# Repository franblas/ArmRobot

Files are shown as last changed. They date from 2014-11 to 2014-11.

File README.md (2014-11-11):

# ArmRobot Project
The ArmRobot project aims to build and control a functional robotic arm using servo motors.
Project realized by Luc F. and Francois B. 

## The C library for STM32 card
A [C library](STM32/) has been developed to communicate with servo motors and control the arm as a whole through a STM32 electronic card.

## The Arduino library for Arduino card
An [Arduino](Arduino/) library has been developed to debug servo motors through an Arduino electronic card.

## Theorical code
A [Matlab](Matlab/) implementation has been done to compute equations for angles, based on the theory of Denhavit-Artenberg.

## Solidworks model
We have built the arm from scratch. [Here] (Solidworks/) you can find the whole model on solidworks we have realized, with every part of the arm.

## Joystick
Move an arm robot is cool, but with a joystick it's cooler ! [Here] (PCB_Joystick/) you can can find the pcb of the joystick, realized with Eagle.

## Project rapport
You can find the whole project rapport in pdf format [here] (https://github.com/franblas/ArmRobot/blob/master/Doc/compte_rendu_bras_de_robot.pdf?raw=true) (It's in french).

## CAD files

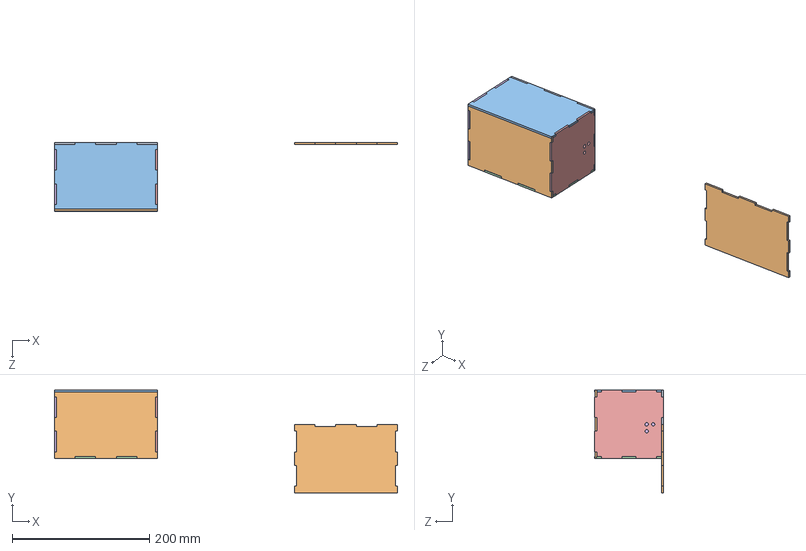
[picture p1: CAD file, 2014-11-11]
Solidworks/piecesassembleesphoto2.SLDASM
499.4 x 150.0 x 100.0 mm
dessous
dessus x 2
arriere1
facegauche1
facedroite1

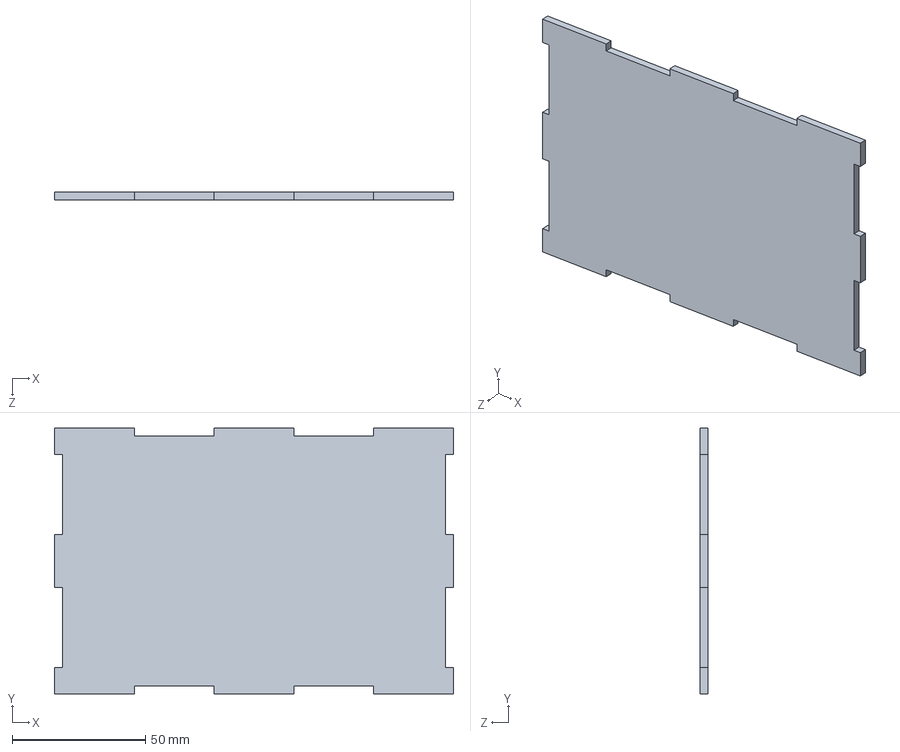
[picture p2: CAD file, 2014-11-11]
Solidworks/dessous.SLDPRT
150.0 x 100.0 x 3.00 mm

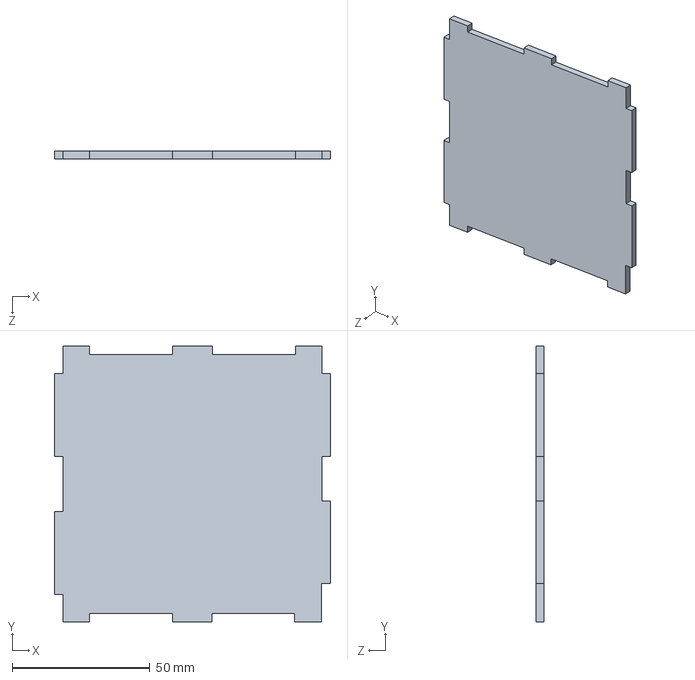
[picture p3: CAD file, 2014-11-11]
Solidworks/facegauche.SLDPRT
100.1 x 100.0 x 3.00 mm

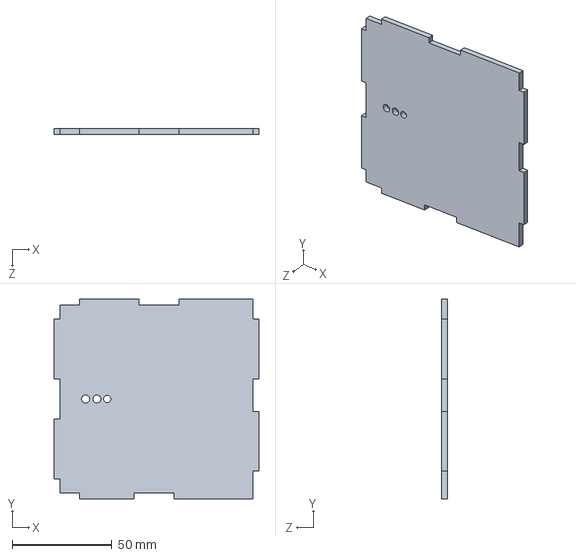
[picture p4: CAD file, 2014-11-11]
Solidworks/facedroite.SLDPRT
102.7 x 100.0 x 3.00 mm

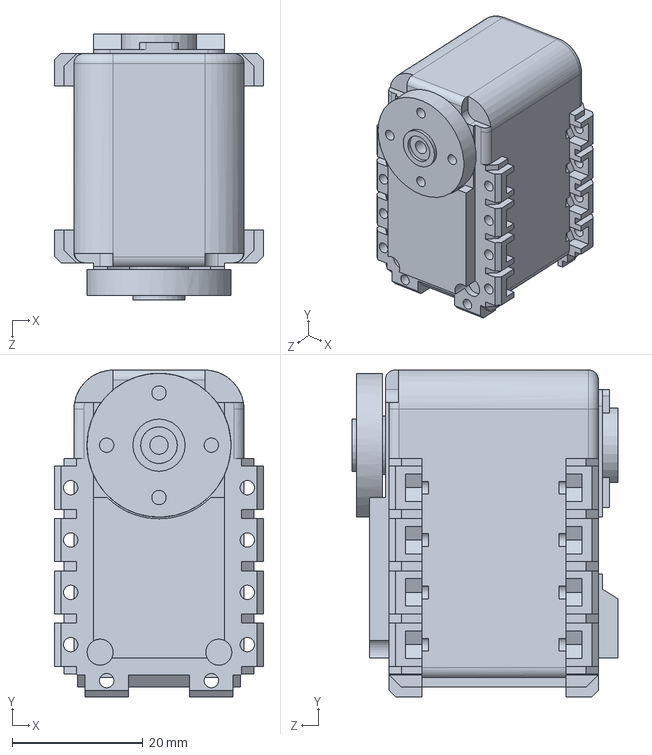
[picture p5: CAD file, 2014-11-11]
Solidworks/AX-12_2.SLDPRT
32.0 x 50.0 x 40.7 mm

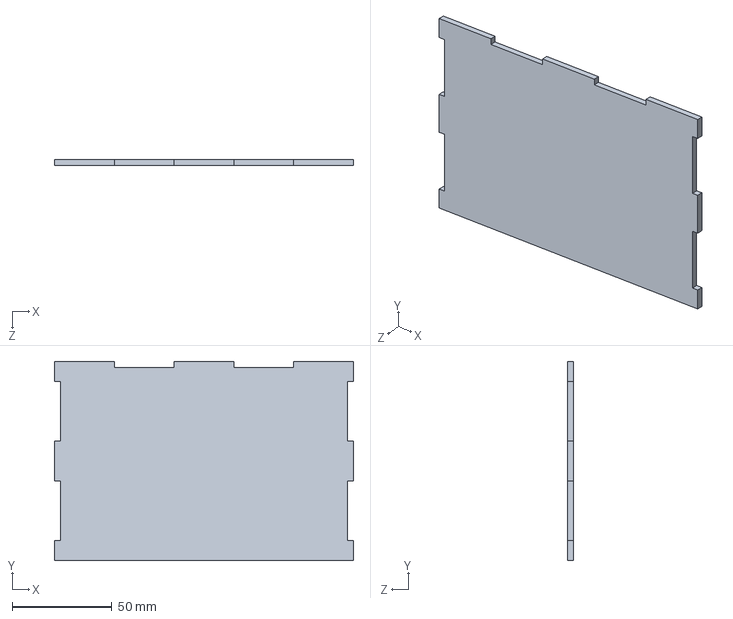
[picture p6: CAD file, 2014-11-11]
Solidworks/dessus.SLDPRT
150.0 x 100.0 x 3.00 mm

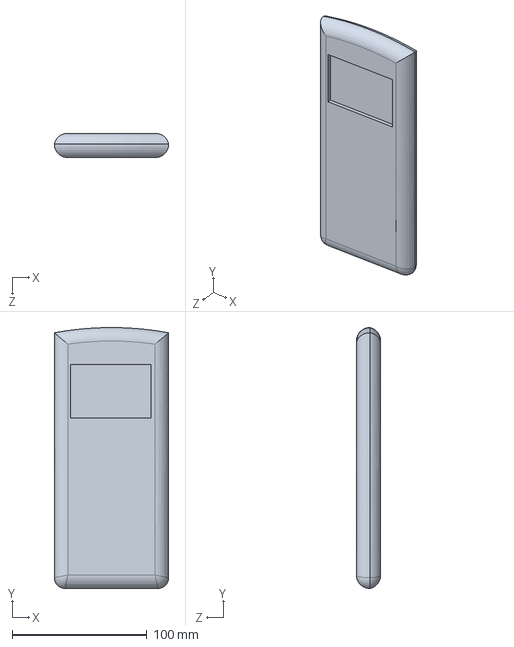
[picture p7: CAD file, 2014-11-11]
Solidworks/arriere.SLDPRT
85.0 x 193.9 x 18.0 mm

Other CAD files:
Solidworks/facedroite1.SLDPRT
Solidworks/Pièce1.SLDPRT
Solidworks/arriere1.SLDPRT
Solidworks/face.SLDPRT
Solidworks/facegauche1.SLDPRT

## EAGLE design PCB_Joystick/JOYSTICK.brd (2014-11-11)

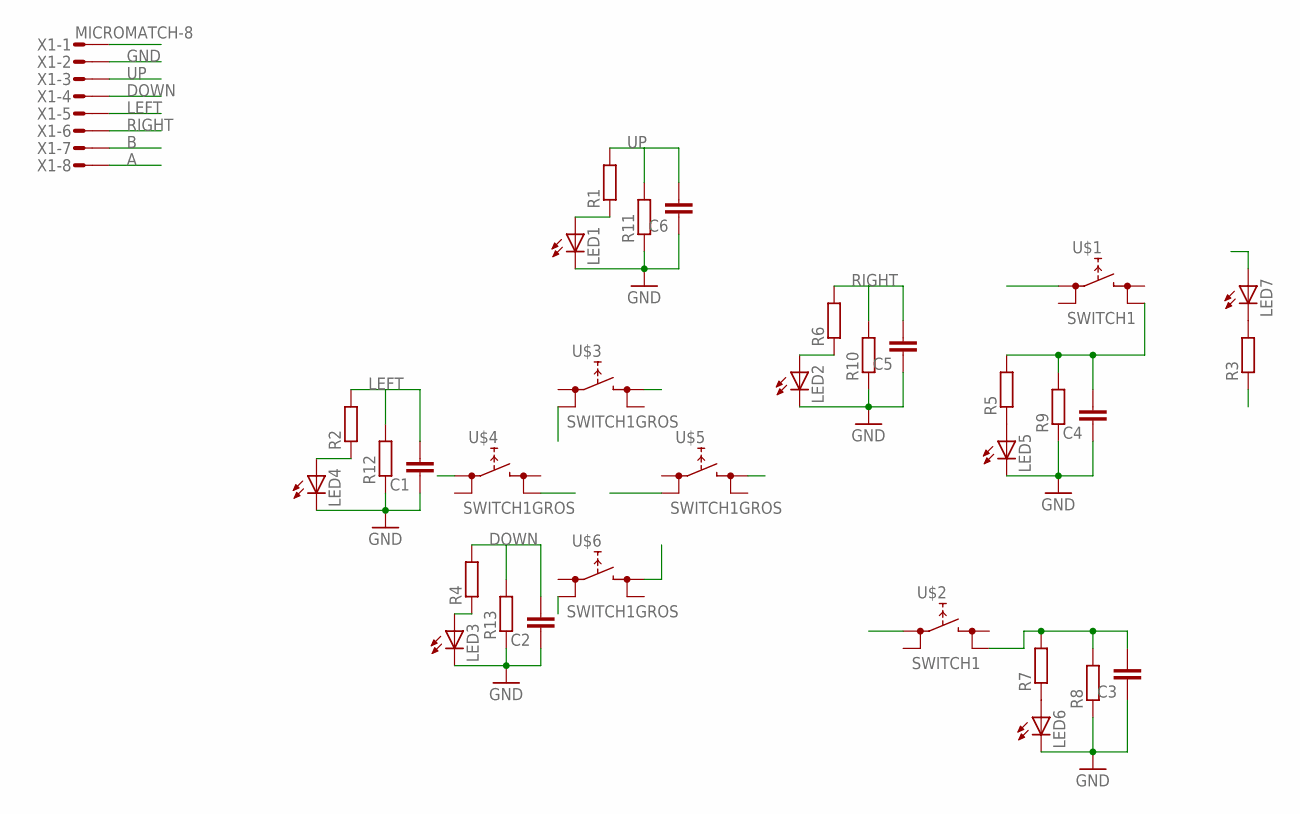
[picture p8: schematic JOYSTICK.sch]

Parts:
C1, C2, C3, C4, C5, C6: C-EUC0805; C0805
LED1, LED2, LED3, LED4, LED5, LED6, LED7: LED3MM
R1, R2, R3, R4, R5, R6, R7, R8, R9, R10, R11, R12, R13: R-EU_R0805; R0805
U$1, U$2: SWITCH1; TL1105
U$3, U$4, U$5, U$6: SWITCH1GROS; REKN
X1: MICROMATCH-8

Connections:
+5V: LED7.A, U$1.1 (0), U$2.1 (0), U$3.1B (0), U$4.2B (1), U$5.1B (0), U$6.2A (1), X1.1
A: C4.2, R5.2, R9.2, U$1.4 (1), X1.8
B: C3.2, R7.2, R8.2, U$2.4 (1), X1.7
DOWN: C2.2, R4.2, R13.2, U$6.1B (0), X1.4
GND: C1.1, C2.1, C3.1, C4.1, C5.1, C6.1, LED1.K (C), LED2.K (C), LED3.K (C), LED4.K (C), LED5.K (C), LED6.K (C), R3.1, R8.1, R9.1, R10.1, R11.1, R12.1, R13.1, X1.2
LEFT: C1.2, R2.2, R12.2, U$4.1A (0), X1.5
unnamed: LED1.A, R1.1
unnamed: LED4.A, R2.1
unnamed: LED7.K (C), R3.2
unnamed: LED3.A, R4.1
unnamed: LED5.A, R5.1
unnamed: LED2.A, R6.1
unnamed: LED6.A, R7.1
RIGHT: C5.2, R6.2, R10.2, U$5.2A (1), X1.6
UP: C6.2, R1.2, R11.2, U$3.2A (1), X1.3

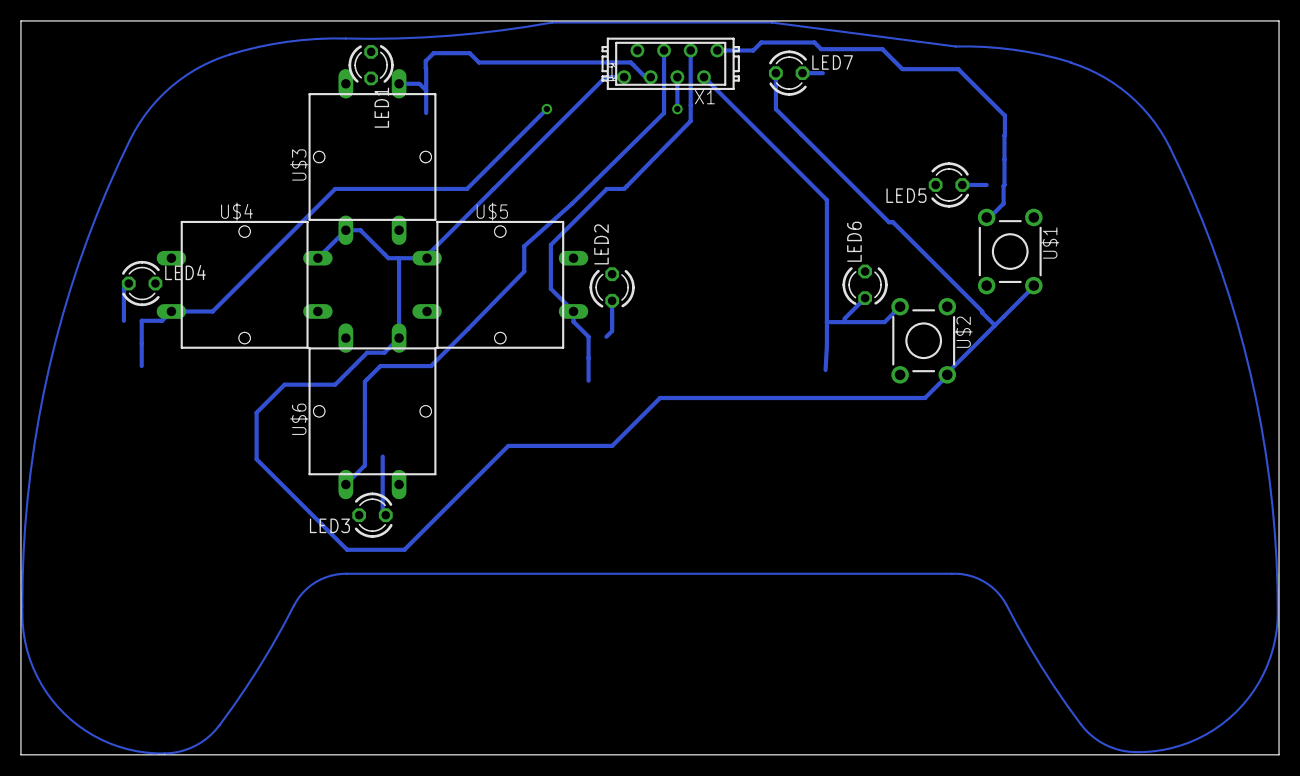
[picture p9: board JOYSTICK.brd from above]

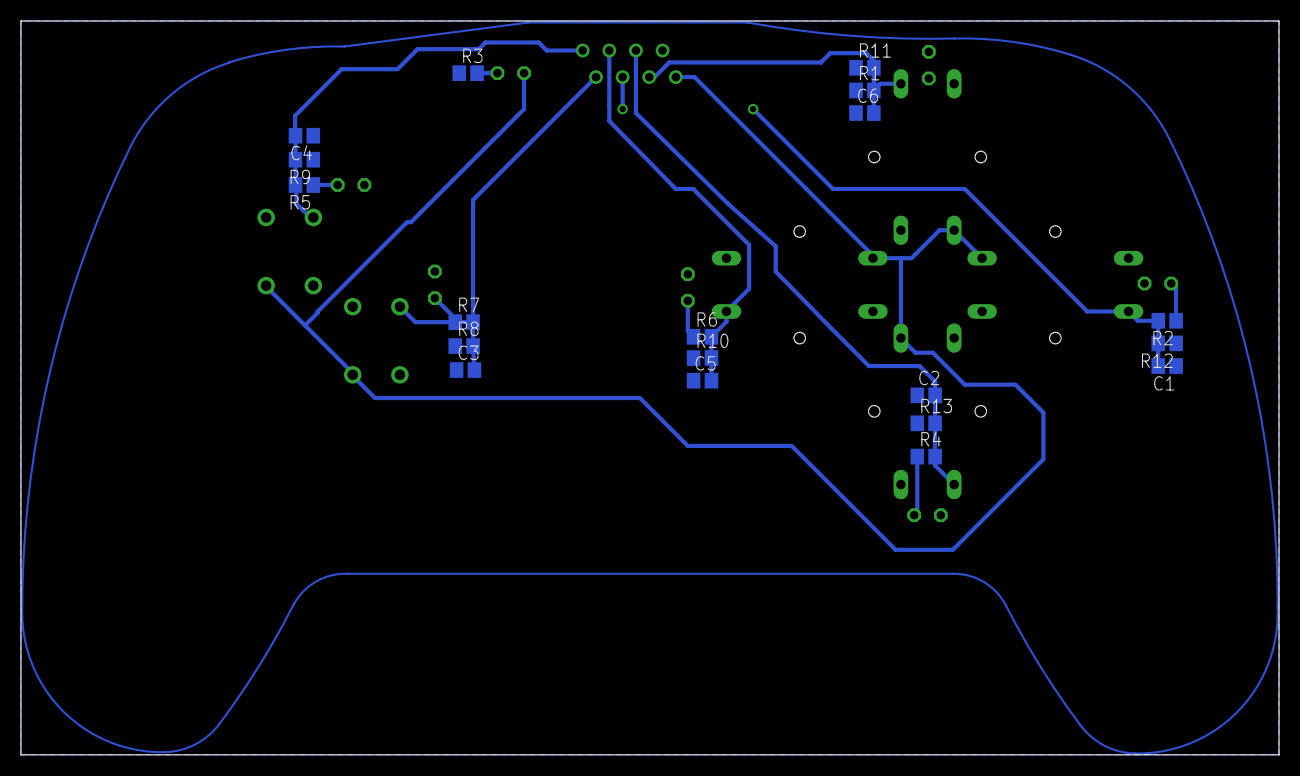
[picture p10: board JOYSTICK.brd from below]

Board: 2 copper layers, 120.0 x 70.0 mm, 33 parts (19 on the bottom side), 15 nets.

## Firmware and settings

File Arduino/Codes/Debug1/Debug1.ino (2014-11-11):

/*	****** Written by François Blas
 	****** Last Modification: 27/04/13 	
	
	Using the Arduino Mega 2560 										
*/

/*
>>>>> Connecter le TX1 (port 18 Arduino Mega 2560) et le RX1 (port 19 Arduino Mega 2560)
sur le data de l'AX12 (TX1 et RX1 ensemble)
>>>>> Pas besoin de resistance de pull-up !!!!!!!!!
*/

//Biblio AX12 Arduino
#include <ax12.h>
#include <BioloidController.h>

//Liste de Baudrates standards pour AX12
long BaudRates[] = {1000000,666667,500000,400000,333333,285714,250000,222222,
200000,181818,166667,153846,142857,133333,125000,117647,111111,105263,100000,
95238,90909,86957,83333,80000,76923,74074,71429,68966,66667,64516,62500,60606,
58824,57143,55556,54054,52632,51282,50000,48780,47619,46512,45455,44444,43478,
42553,41667,40816,40000,39216,38462,37736,37037,36364,35714,35088,34483,33898,
33333,32787,32258,31746,31250,30769,30303,29851,29412,28986,28571,28169,27778,
27397,27027,26667,26316,25974,25641,25316,25000,24691,24390,24096,23810,23529,
23256,22989,22727,22472,22222,21978,21739,21505,21277,21053,20833,20619,20408,
20202,20000,19802,19608,19417,19231,19048,18868,18692,18519,18349,18182,18018,
17857,17699,17544,17391,17241,17094,16949,16807,16667,16529,16393,16260,16129,
16000,15873,15748,15625,15504,15385,15267,15152,15038,14925,14815,14706,14599,
14493,14388,14286,14184,14085,13986,13889,13793,13699,13605,13514,13423,13333,
13245,13158,13072,12987,12903,12821,12739,12658,12579,12500,12422,12346,12270,
12195,12121,12048,11976,11905,11834,11765,11696,11628,11561,11494,11429,11364,
11299,11236,11173,11111,11050,10989,10929,10870,10811,10753,10695,10638,10582,
10526,10471,10417,10363,10309,10256,10204,10152,10101,10050,10000,9950,9901,
9852,9804,9756,9709,9662,9615,9569,9524,9479,9434,9390,9346,9302,9259,9217,
9174,9132,9091,9050,9009,8969,8929,8889,8850,8811,8772,8734,8696,8658,8621,
8584,8547,8511,8475,8439,8403,8368,8333,8299,8264,8230,8197,8163,8130,8097,
8065,8032,8000,7968,7937,7905,7874,7843};

int pos;    // position AX12 
int id;   // Identifiant AX12
int bio;  // baudrate AX12

//Initialisation communication
BioloidController bioloid=BioloidController(1000000);


void setup()
{
   pinMode(13, OUTPUT);
    pos = 511;
    bio=0;
    id = 1;
}

void loop()
{
  for(bio=0;bio<=254;bio++)
  {
    ax12Init(BaudRates[bio]); //Initialisation nouveau Baudrate
    for(id=1;id<256;id++)
    {
        digitalWrite(13,HIGH);//Allumage LED arduino
        SetPosition(id,pos); //Changment position si bon baudrate
        delay(25);
        SetPosition(id,309);//Changment position si bon baudrate
        delay(100);
        ax12SetRegister(id,3,1);//Reset ID a 1
        delay(100);
        ax12SetRegister(id,4,1);//Reset baudrate a 1 Mbps
        delay(25);
    }
    digitalWrite(13, LOW);//La led clignote quand tout les identifiants sont testes (pour un baudrate donne)
    delay(200);
  }
    digitalWrite(13, LOW);
    delay(150000000);
    //ax12SetRegister2(servo_id, regstart, data);
}

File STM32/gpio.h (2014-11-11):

/*	****** Written by François Blas
 	****** Last Modification: 25/05/13 	
	
	Using the stm32f10x lib needs a configuration. You need to put STM32F10X_LD_VL in 
	Project\Option for Target\C/C++\Define 										
	
	The datasheet is needed to find the best option for your project and to know the global 
	fonctionnement of each peripherial.	*/ 
	
#ifndef GPIO_H_INCLUDED
#define GPIO_H_INCLUDED

//////////////////////////////////////////////////////
//////////////////////////////////////////////////////
//////////////////// Macros //////////////////////////
//////////////////////////////////////////////////////
//////////////////////////////////////////////////////

/* GPIOx */
#define GPIO_A 1
#define GPIO_B 2
#define GPIO_C 3

/* OUTPUT */
#define GENERAL_PUSHPULL 4
#define ALTERNATE_PUSHPULL 5
#define SPEED_50 6
#define SPEED_10 7
#define SPEED_2 8
#define ALTERNATE_OPENDRAIN 9
#define GENERAL_OPENDRAIN 10

/* INPUT */
#define ANALOGUE 11
#define FLOATING 12
#define PULLUPDOWN 13
#define SPEED_NO 14

/* AUTRES */
#define SET 15
#define RESET 16

//////////////////////////////////////////////////////
//////////////////////////////////////////////////////
/////////////////// Fonctions ////////////////////////
//////////////////////////////////////////////////////
//////////////////////////////////////////////////////

/**
Configurations preliminaires
**/
void gpio_clock(int gpiox);
void gpioa_crl(int gpiox, int num, int speed, int mode);
void gpioa_crh(int gpiox, int num, int speed, int mode);
void gpiob_crl(int gpiox, int num, int speed, int mode);
void gpiob_crh(int gpiox, int num, int speed, int mode);
void gpioc_crl(int gpiox, int num, int speed, int mode);
void gpioc_crh(int gpiox, int num, int speed, int mode);

/**
------------------------------------------------
---------- Configuration finale GPIOx ----------
------------------------------------------------
-> gpiox : nom du port (GPIO_A, GPIO_B, GPIO_C)
-> numport : numero du port (0 a 15)
-> speed : freq du port (SPEED_2 (2MHz), SPEED_10 (10MHz), SPEED_50 (50MHz))
-> mode : mode du port 
	 (Output : GENERAL_PUSHPULL, GENERAL_OPENDRAIN, ALTERNATE_PUSHPULL, ALTERNATE_OPENDRAIN)
	 (Input : ANALOGUE, FLOATING, PULLUPDOWN) 
-------------------------------------------------
**/
void gpio_config(int gpiox, int numport, int speed, int mode);

/**
-------------------------------------------------
------------- Set/Reset data GPIOx --------------
-------------------------------------------------
-> gpiox : nom du port (GPIO_A, GPIO_B, GPIO_C)
-> num : numero du port (0 a 15)
-> action : set ou reset data (SET, RESET)
-------------------------------------------------
**/
void gpio_bsrr(int gpiox, int num, int action);

/**
-------------------------------------------------
----------- Read input data GPIOx ---------------
-------------------------------------------------
Renvoi 0 si pas de data, 1 sinon
-> gpiox : nom du port (GPIO_A, GPIO_B, GPIO_C)
-> num : numero du port (0 a 15)
-------------------------------------------------
**/
int gpio_idr(int gpiox, int num);

#endif // GPIO_H_INCLUDED

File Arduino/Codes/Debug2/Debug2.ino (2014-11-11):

/*	****** Written by François Blas
 	****** Last Modification: 27/04/13 	
	
	Using the Arduino Mega 2560 										
*/

/*
>>>>> Connecter le TX1 (port 18 Arduino Mega 2560) et le RX1 (port 19 Arduino Mega 2560)
sur le data de l'AX12 (TX1 et RX1 ensemble)
>>>>> Pas besoin de resistance de pull-up !!!!!!!!!
*/

/*
Decommenter la ligne sous "Changer l'identifiant de l'AX12" puis mettre le nouvel identifiant de l'AX12 a la place de newID
Televerser vers l'AX12
Recommenter la ligne
Tester le nouvel identifiant (changer id dans setup)
Decommenter la ligne sous "Mettre baudrate a 500k" avec id=votre nouvel identifiant
Televerser vers l'AX12
Recommenter la ligne
Modifier BioloidController(1000000) par BioloidController(500000)
Tester l'AX12
*/

//Biblio AX12 Arduino
#include <ax12.h>
#include <BioloidController.h>

int pos;    // position AX12 
int id;     // Identifiant AX12

//Initialisation de la communication
//Une fois le baudrate d'un AX12 modifié, changer la valeur contenue dans BioloidController() 
BioloidController bioloid=BioloidController(1000000);


void setup()
{
  pinMode(13, OUTPUT);
    pos = 511;
    id = 4;
}

void loop()
{
    digitalWrite(13,HIGH);
    SetPosition(id,pos); //Changment position 
    delay(25);
    SetPosition(id,402); //Changment position 
    delay(100);
    /* Changer l'identifiant de l'AX12 */
    //ax12SetRegister(id,3,newID);
    delay(100);
    /* Mettre baudrate a 500k */
    //ax12SetRegister(id,4,3);
    delay(25);
    
    digitalWrite(13, LOW);
    delay(200);

    //ax12SetRegister(servo_id, regstart, data);
}

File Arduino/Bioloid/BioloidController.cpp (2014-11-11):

/*
  BioloidController.cpp - arbotiX Library for Bioloid Pose Engine
  Copyright (c) 2008,2009 Michael E. Ferguson.  All right reserved.
*/

#include <Arduino.h> // we need this for the serial port defines

#include <avr/pgmspace.h>
#include "BioloidController.h"

/* initializes serial1 transmit at baud, 8-N-1 */
BioloidController::BioloidController(long baud){
    int i;
    for(i=0;i<AX12_MAX_SERVOS;i++)
        pose[i] = 512;
    interpolating = 0;
    playing = 0;
    lastframe = millis();
    ax12Init(baud);  
}

/* load a named pose from FLASH into nextpose. */
void BioloidController::loadPose( const unsigned int * addr ){
    int i;
    poseSize = pgm_read_word_near(addr); // number of servos in this pose
    for(i=0; i<poseSize; i++)
        nextpose[i] = pgm_read_word_near(addr+1+i) << BIOLOID_SHIFT;
}
/* read in current servo positions to the pose. */
void BioloidController::readPose(){
    for(int i=0;i<poseSize;i++){
        pose[i] = ax12GetRegister(i+1,AX_PRESENT_POSITION_L,2)<<BIOLOID_SHIFT;
        delay(25);   
    }
}
/* write pose out to servos using sync write. */
void BioloidController::writePose(){
    int temp;
    int count = poseSize;
    int length = 4 + (poseSize * 3);   // 3 = id + pos(2byte)
    int checksum = 254 + length + AX_SYNC_WRITE + 2 + AX_GOAL_POSITION_L;
    setTXall();
    ax12write(0xFF);
    ax12write(0xFF);
    ax12write(0xFE);
    ax12write(length);
    ax12write(AX_SYNC_WRITE);
    ax12write(AX_GOAL_POSITION_L);
    ax12write(2);
    while(count > 0){
        count--;
        temp = pose[count] >> BIOLOID_SHIFT;
        checksum += (temp&0xff) + (temp>>8) + count + 1;
        ax12write(count + 1);
        ax12write(temp&0xff);
        ax12write(temp>>8);
    } 
    ax12write(0xff - (checksum % 256));
    setRX(0);
}

/* set up for an interpolation from pose to nextpose over TIME 
    milliseconds by setting servo speeds. */
void BioloidController::interpolateSetup(int time){
    int i;
    int frames = (time/BIOLOID_FRAME_LENGTH) + 1;
    lastframe = millis();
    // set speed each servo...
    for(i=0;i<poseSize;i++){
        if(nextpose[i] > pose[i]){
            speed[i] = (nextpose[i] - pose[i])/frames + 1;
        }else{
            speed[i] = (pose[i]-nextpose[i])/frames + 1;
        }
    }
    interpolating = 1;
}
/* interpolate our pose, this should be called at about 30Hz. */
void BioloidController::interpolateStep(){
    if(interpolating == 0) return;
    int i;
    int complete = poseSize;
    while(millis() - lastframe < BIOLOID_FRAME_LENGTH);
    lastframe = millis();
    // update each servo
    for(i=0;i<poseSize;i++){
        int diff = nextpose[i] - pose[i];
        if(diff == 0){
            complete--;
        }else{
            if(diff > 0){
                if(diff < speed[i]){
                    pose[i] = nextpose[i];
                    complete--;
                }else
                    pose[i] += speed[i];
            }else{
                if((-diff) < speed[i]){
                    pose[i] = nextpose[i];
                    complete--;
                }else
                    pose[i] -= speed[i];                
            }       
        }
    }
    if(complete <= 0) interpolating = 0;
    writePose();      
}

/* get a servo value in the current pose */
int BioloidController::getCurPose(int id){
    return ((pose[id-1]) >> BIOLOID_SHIFT);
}
/* get a servo value in the next pose */
int BioloidController::getNextPose(int id){
    return ((nextpose[id-1]) >> BIOLOID_SHIFT);
}
/* set a servo value in the next pose */
void BioloidController::setNextPose(int id, int pos){
    nextpose[id-1] = (pos << BIOLOID_SHIFT);
}

/* play a sequence. */
void BioloidController::playSeq( const transition_t  * addr ){
    sequence = (transition_t *) addr;
    // number of transitions left to load
    transitions = pgm_read_word_near(&sequence->time);
    sequence++;    
    // load a transition
    loadPose((const unsigned int *)pgm_read_word_near(&sequence->pose));
    interpolateSetup(pgm_read_word_near(&sequence->time));
    transitions--;
    playing = 1;
}
/* keep playing our sequence */
void BioloidController::play(){
    if(playing == 0) return;
    if(interpolating > 0){
        interpolateStep();
    }else{  // move onto next pose
        sequence++;   
        if(transitions > 0){
            loadPose((const unsigned int *)pgm_read_word_near(&sequence->pose));
            interpolateSetup(pgm_read_word_near(&sequence->time));
            transitions--;
        }else{
            playing = 0;
        }
    }
}
